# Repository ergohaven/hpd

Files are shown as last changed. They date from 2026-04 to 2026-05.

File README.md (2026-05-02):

## High Plains Drifter is a modular, curved mechanical keyboard that is ready to change the way you think about ergonomics in typing!  
*Innovative design that allows easy access to all keys, and specially designed modules that make the keyboard a unique tool, exclusively for your purpose*

HPD v2

## Design philosphy
This keyboard was designed with FDM printing in mind, the goal was to create a perfect curved case that can be easily printed and looks aesthetically pleasing with minimal amount of so called "steps" that plague similar 3D keyboards like Dactyl Manuform, it's design is similar to the [Velvet v3](https://github.com/ergohaven/velvet) keyboard but with 60% layout and addition of various interchangeable modules
HPD v2
HPD v2

## Features
- Modular, ergonomic 3D design
- 60 fully programmable keys, 15 additional layers for all your tasks
- Powered by RP2040 Zero and QMK firmware
- Hotswappable PCB (MX sockets) 
- Type-C output for connection between halves
- Easily remap any key and customize your keyboard with [Vial](https://eh.industries/vial) 
- [Firmware](https://github.com/ergohaven/keymap_hub) is being constantly updated, get the latest QMK features for your keyboard from us ♥️  

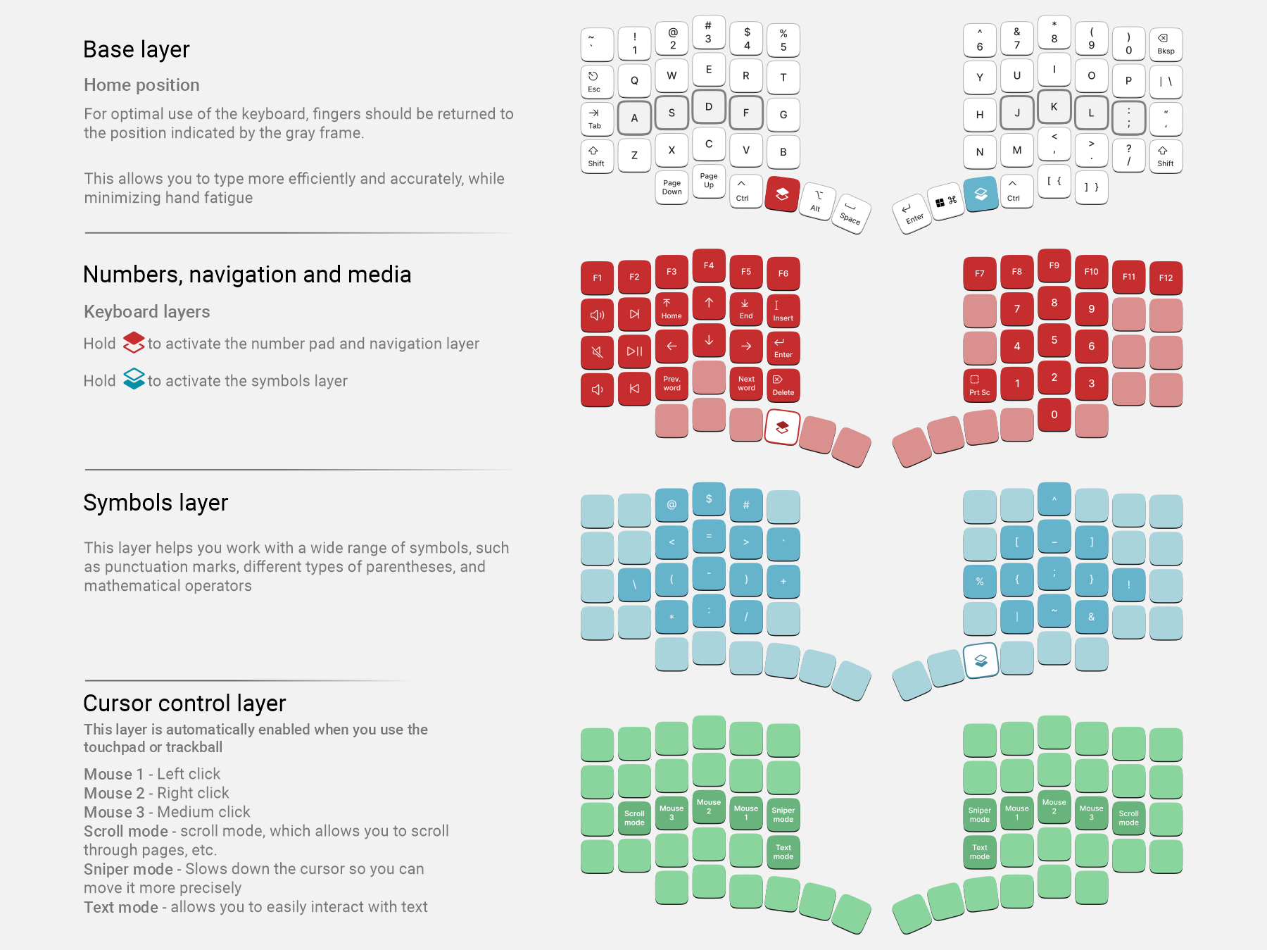
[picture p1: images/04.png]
HPD v2


## This repo contains all files related to this keyboard
PCB and schematic can be found [here](https://oshwlab.com/yuriiq/hpdv2)

### Build guide (handwired)
- [English](https://github.com/ergohaven/hpd/blob/main/handwired/handwired.en.md)
- [Russian](https://github.com/ergohaven/hpd/blob/main/handwired/handwired.md)

### Build guide (PCB is required)
- [English](https://github.com/ergohaven/hpd/blob/main/build_guide/build_guide_en.md)
- [Russian](https://github.com/ergohaven/hpd/blob/main/build_guide/build_guide_ru.md)

### BOM
#### Main case
| Components | Quantity (pcs) |
| --- | ---: |
| Switchplate + thumb keys + MCU holder PCBs | 1 |
| RP2040 Zero MCU | 2 |
| MX Hotswap sockets | 60 |
| 1N4148W Diodes (SOD-123) | 60 |
| Male Pin Header Connector: 11 Pins, 2.54mm, 90 degree | 2 |
| Female Header Sockets: 11 Pins, 2.54mm, 90 degree | 2 |
| Female Header Sockets: 9 Pins, 2.54mm, 90 degree | 2 |
| Socket SH1.0 5 Pins, 1.00mm | 4 |
| Cable connector SH1.0 5 Pins, 1mm, 100mm, double head | 2 |
| 1 - 100 kOhm resistors (0805) | 2 |
| USB Type-C daughterboard: 1.6mm thick | 2 |
| M2x4 Screws | 32 |
| M3x5 Inserts | 10 |
| M3x4 Screws | 10 |
| Magnets (5х10х2mm) | 4 |
| 3M bumpons (8mm) | 4 |

#### Encoder module
| Components | Quantity (pcs) |
| --- | ---: |
| Encoder PCB | 1 |
| Encoder EC11 | 1 |
| Encoder cap | 1 |
| Male Pin Header Connector: 9 Pins, 2.54mm, 90 degree | 1 |
| 1N4148W Diodes (SOD-123) | 1 |
| LED SK6812 mini-e | 1 |
| Magnets (5х10х2mm) | 2 |
| 3M bumpons (8mm) | 2 |

#### Touchpad module
| Components | Quantity (pcs) |
| --- | ---: |
| Touchpad PCB | 1 |
| Azoteq TPS43 | 1 |
| Male Pin Header Connector: 9 Pins, 2.54mm, 90 degree | 1 |
| Connector PH2.0 4 pins, 2mm, 90 degree | 1 |
| Cable connector PH2.0 4 Pins, 2mm, 6mm, one head | 1 |
| Magnets (5х10х2mm) | 2 |
| plate 40x43x1 mm with rounding 3mm | 1 |
| PVC 40x43 mm sticker with rounding 3mm | 1 |
| 3M bumpons (8mm) | 2 |

#### Trackball module
| Components | Quantity (pcs) |
| --- | ---: |
| Trackball PCB | 1 |
| PWM3389 sensor | 1 |
| TPS73601DBVR | 1 |
| Male Pin Header Connector: 9 Pins, 2.54mm, 90 degree | 1 |
| Resistor 0805 10 kOm | 1 |
| Resistor 0805 39 Om | 1 |
| Resistor 0805 37.4 kOm | 1 |
| Resistor 0805 63.4 kOm | 1 |
| Capacitor 0805 100 nF | 3 |
| Capacitor 0805 1 uF | 1 |
| Capacitor 0805 4.7 uF | 1 |
| Capacitor 0805 10 uF | 1 |
| Magnets (5х10х2mm) | 2 |
| 3M bumpons (8mm) | 2 |
| 38mm billiard ball | 1 |
| Ceramic Bearing Balls (3mm) | 3 |

## License 

The files in this repository are licensed under a Creative Commons Attribution-NonCommercial-ShareAlike 4.0 International License.

## Firmware
- [Pre-compiled files][1]
- [Source code][2]

[1]: https://github.com/ergohaven/keymap_hub
[2]: https://github.com/ergohaven/vial-qmk/tree/vial/keyboards/ergohaven

## Availability
The complete keyboard (not a diy kit!) is available for purchase at [eh.industries](https://eh.industries/)

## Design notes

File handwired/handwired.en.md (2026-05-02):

# High Plains Drifter v2 — handwired keyboard assembly guide



## Before you start

This guide describes how to assemble the High Plains Drifter v2 keyboard without PCBs and without complex soldering. It is intended for users who want to build the curved HPD v2 split keyboard at home with minimal cost for parts and tools.

> ⚠️ This guide does not cover assembly of modules for HPD v2, because handwired mounting of components and connectors is not reliable for modules.

## Useful links

- [HPD v2 case for 3D printing (STL)](stl)
- [HPD v2 case model for editing (STEP)](step)
- [HPD v2 circuit schematic](https://oshwlab.com/yuriiq/hpdv2)
- [Firmware](https://github.com/ergohaven/keymap_hub)
- [QMK documentation](https://docs.ergohaven.xyz/qmk/)

---

## Components

| Name | Quantity (pcs) |
| --- | ---: |
| RP2040 Zero MCU | 2 |
| USB Type-C daughterboard: 1.6mm thick | 2 |
| 1N4148 diodes | 60 |
| 1 - 100 kOhm resistors | 2 |
| Hotswap sockets | 60 |
| Switches | 60 |
| Keycaps | 60 |
| M3x5 inserts | 10 |
| M3x4 screws | 10 |
| 3M bumpons (8mm) | 10 |

<details>
<summary><strong>➕ Component appearance</strong></summary>

| Component | Appearance |
| --- | --- |
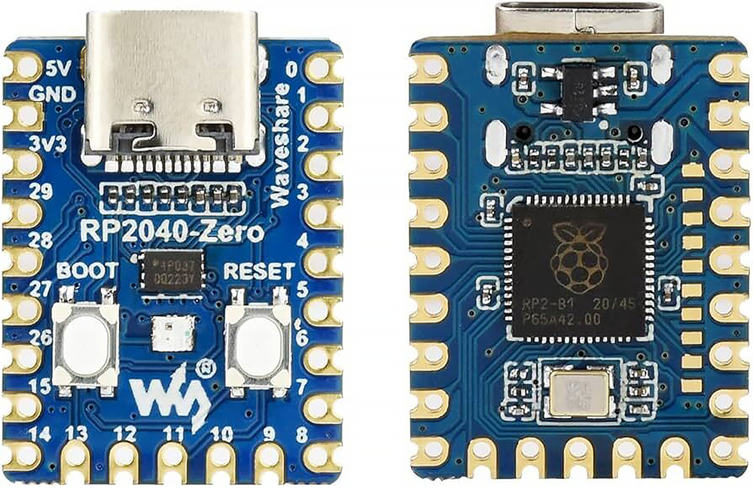
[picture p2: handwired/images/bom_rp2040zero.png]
| RP2040 Zero MCU |  |
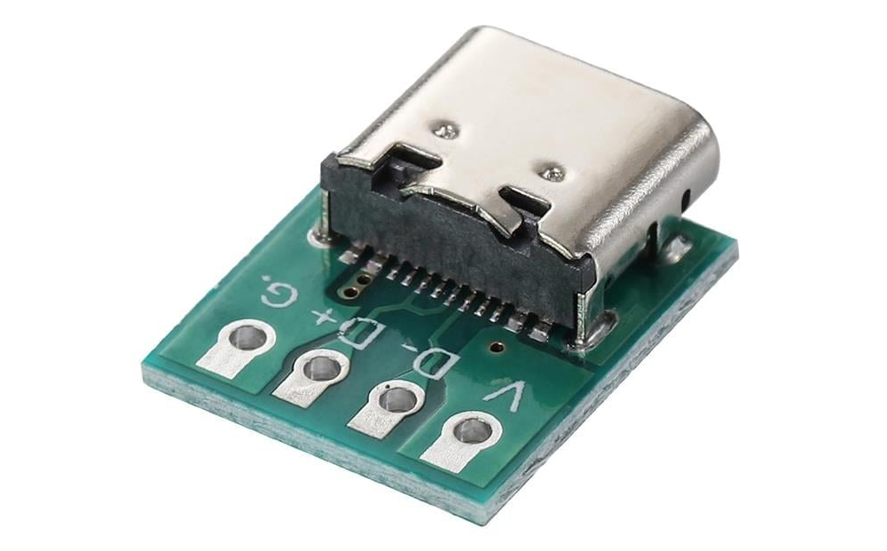
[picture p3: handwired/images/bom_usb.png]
| USB Type-C daughterboard: 1.6mm thick |  |
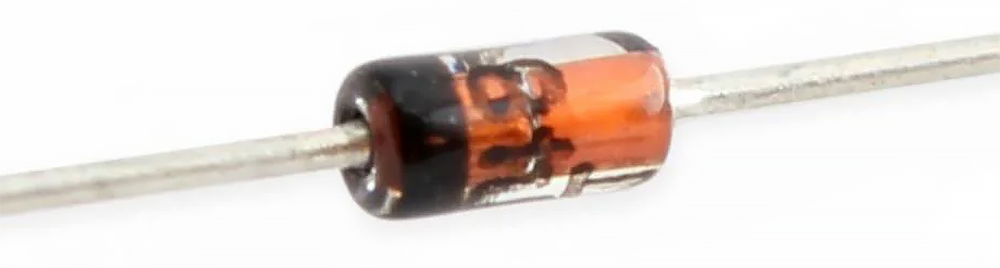
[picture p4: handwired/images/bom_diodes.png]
| 1N4148 diodes |  |
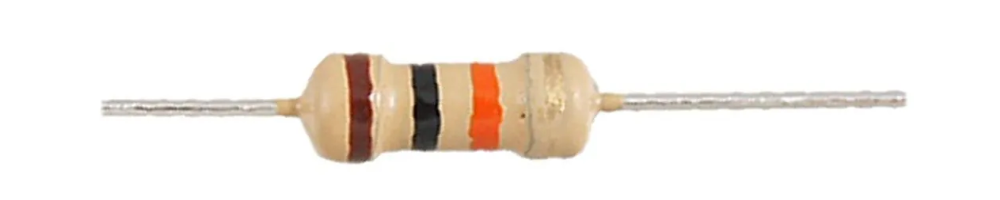
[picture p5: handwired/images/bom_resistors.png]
| 1 - 100 kOhm resistors |  |
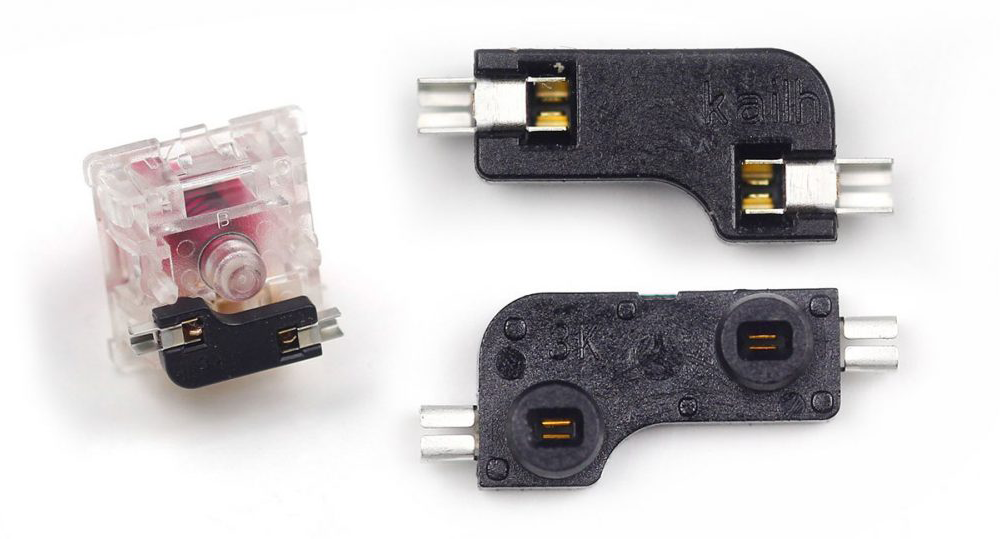
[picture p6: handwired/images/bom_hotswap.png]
| Hotswap sockets |  |
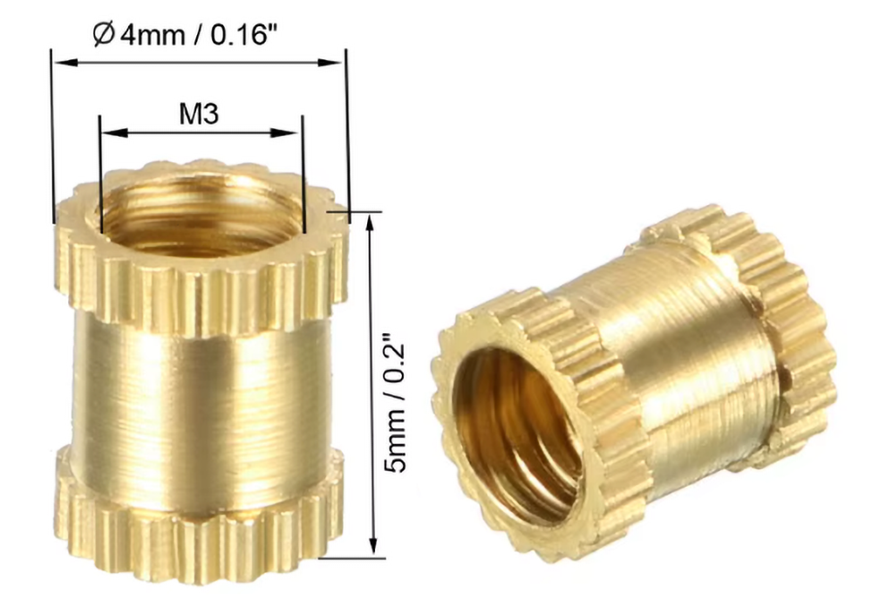
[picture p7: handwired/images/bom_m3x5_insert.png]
| M3x5 inserts |  |
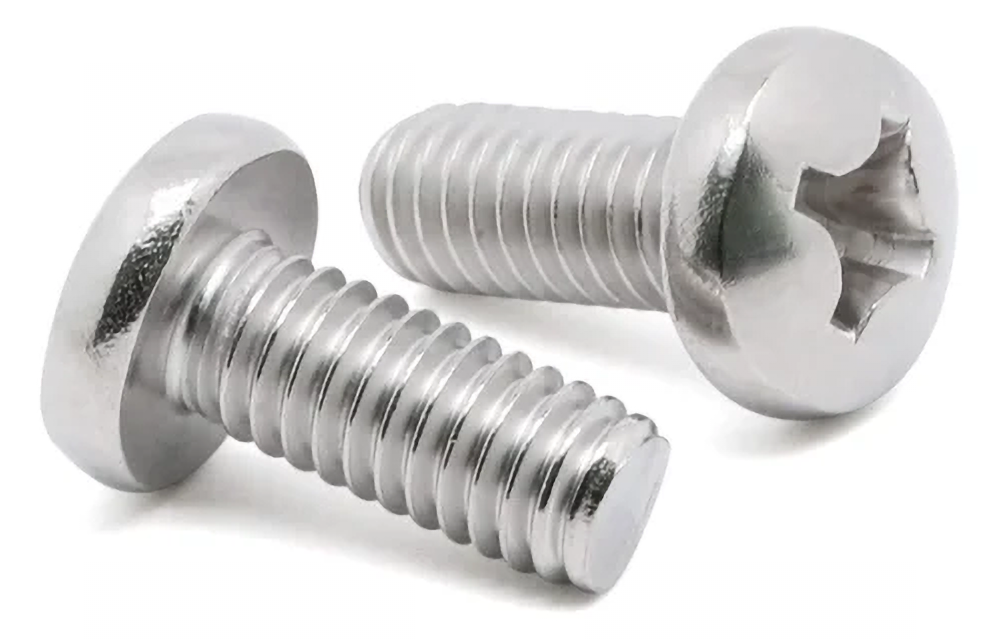
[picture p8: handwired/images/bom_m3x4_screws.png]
| M3x4 screws |  |
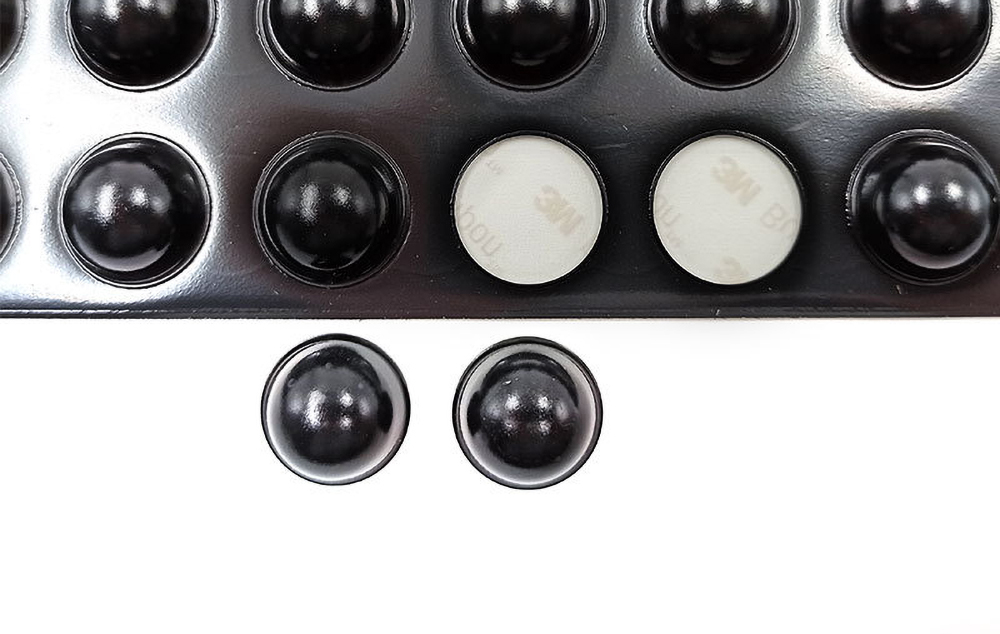
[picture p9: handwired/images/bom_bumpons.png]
| 3M bumpons (8mm) |  |

</details>

---

## Tools and consumables

- 3D printer
- Soldering iron
- Tweezers
- Side cutters
- Screwdriver
- Craft knife
- Solder
- Filament
- Solid-core wire

---

## Assembly steps

### Step 1. Prepare the case, install switches and hotswaps

Print and prepare the [case](stl) on a 3D printer, heat-set the M3x5 inserts, and install the switches and hotswap sockets.



<details>
<summary><strong>➕ Detailed description</strong></summary>

Remove the supports from the case.



Any thin plastic strands in the switch mounting slots can be melted with a lighter.



Heat-set the metal inserts with a soldering iron.




Check that the inserts match the holes in the case cover.



Install the switches on both halves.

> 💡 Insert the switches contact-side down in the top row for easier assembly.




Install the hotswaps on both halves.

> 💡 For the switches in the top row, rotate the hotswaps by 180 degrees.




</details>

---

### Step 2. Prepare the hotswap sockets for soldering

Next, we need to connect all hotswap sockets by columns and rows.

We will connect the rows using 1N4148 diodes. For this, bend the lead on the anode side and trim it, leaving 5–7 mm.



<details>
<summary><strong>➕ Detailed description</strong></summary>

Bend the anode-side lead about 90 degrees.

> ⚠️ The black stripe on the diode marks the cathode; the anode is not marked on the body.



Clip the lead, leaving 5–7 millimeters.



</details>

In this guide we will connect the columns with wires. Prepare them in the required way.

> 💡 You can choose another connection method, for example, use the trimmed diode leads.



<details>
<summary><strong>➕ Detailed description</strong></summary>

Prepare 12 wires about 20 centimeters long. Prepare 8 of them as follows:

- Strip about 15 millimeters of insulation from the end of the wire.



- Make a cut in the insulation about 22 millimeters from the end and slide the insulation toward the end of the wire.



- Make another cut in the insulation about 22 millimeters further and slide the insulation toward the end of the wire.



- Repeat this a third and fourth time. In the end, you should get a wire with 5 exposed segments on the conductor.



For the remaining 4 wires, do the same but with one segment fewer.



</details>

---

### Step 3. Solder the columns and rows

Connect the columns by soldering wires to one of the hotswap socket pins.




<details>
<summary><strong>➕ Detailed description</strong></summary>

> 💡 For convenience, choose one side of the hotswaps for connecting the columns and pre-tin the hotswap contacts with solder.

> ⚠️ Column numbering starts from the side with the USB opening.

The two outer columns (5 and 6) are soldered with wires that have 4 segments, while columns 1–4 use wires with 5 segments prepared in step 2.

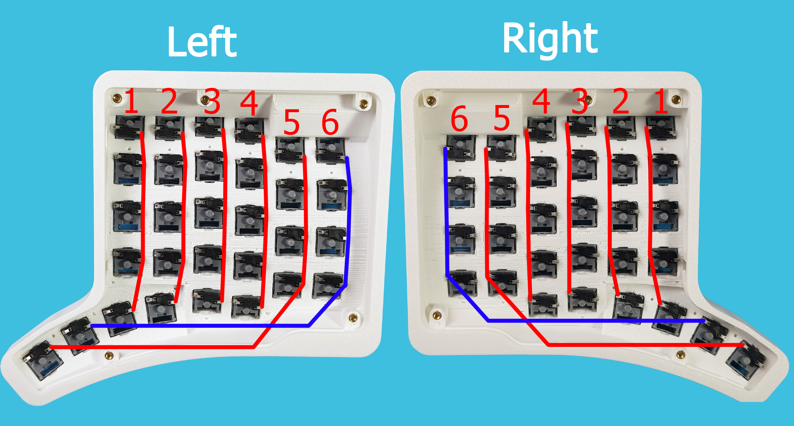
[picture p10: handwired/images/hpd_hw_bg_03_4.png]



Do the same for the right half, mirroring the wire-soldering position.



</details>

Next, connect the rows by soldering 1N4148 diodes with the anode to the second pin of each hotswap socket, and solder a common wire for each row.




<details>
<summary><strong>➕ Detailed description</strong></summary>

Solder the diodes prepared in step 2 to the free hotswap contact with the anode side.

> ⚠️ Row numbering starts from top to bottom.

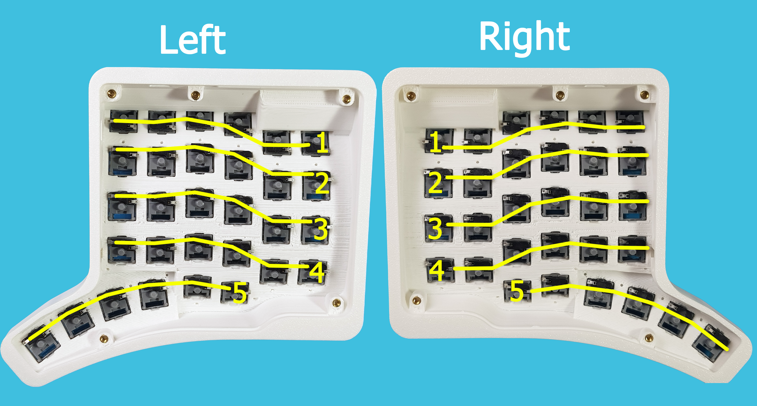
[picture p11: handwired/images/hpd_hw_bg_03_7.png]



Join the cathode leads together into a common trace.



Solder a wire of about 15 centimeters to the common trace.



Repeat these steps for all rows on the left and right halves.

</details>

---

### Step 4. Assemble the holders (controllers)

To assemble the holder (controller), we need two RP2040 Zero controllers, two USB Type-C daughterboards, two 1 - 100 kOhm resistors, and some wires.

Connect everything with wires according to the diagram.

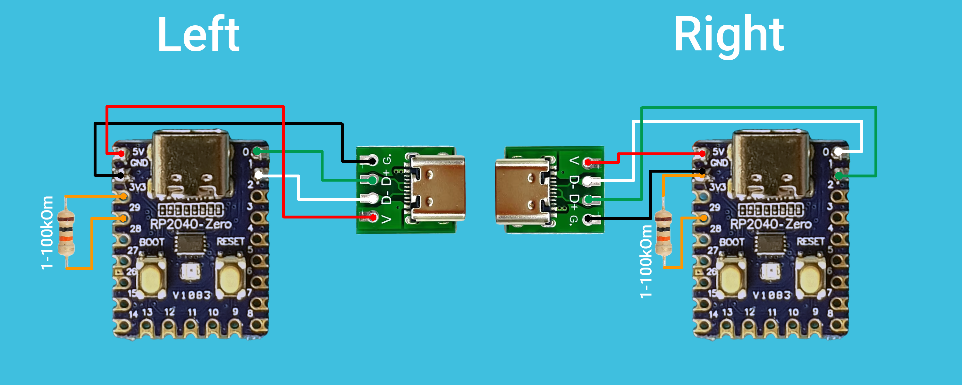
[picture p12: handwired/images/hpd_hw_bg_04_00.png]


First, solder the wires to the USB Type-C daughterboards. For convenience, it is better to use wires of different colors.



Then solder the USB Type-C daughterboards to the RP2040 Zero controller boards.

> ⚠️ On the left and right halves, D- and D+ **are swapped**!

**Left half:**

| USB contact | RP-ZERO pin |
|---|---|
| VCC | 5V |
| GND | GND |
| D− | 0 |
| D+ | 1 |



**Right half:**

| USB contact | RP-ZERO pin |
|---|---|
| VCC | 5V |
| GND | GND |
| D− | 1 |
| D+ | 0 |



Now solder the 1 - 100 kOhm resistors to the RP2040 Zero controllers. This is needed so that the computer can correctly detect which half is connected.

- **Left half:** one end of the resistor → **3V3** pin, the other → **29** pin



- **Right half:** one end of the resistor → **GND** pin, the other → **29** pin



---

### Step 5. Solder the holders (controllers) to the keyboard halves

In this step we will connect the columns and rows to the controller.

Connect everything with wires according to the diagram.

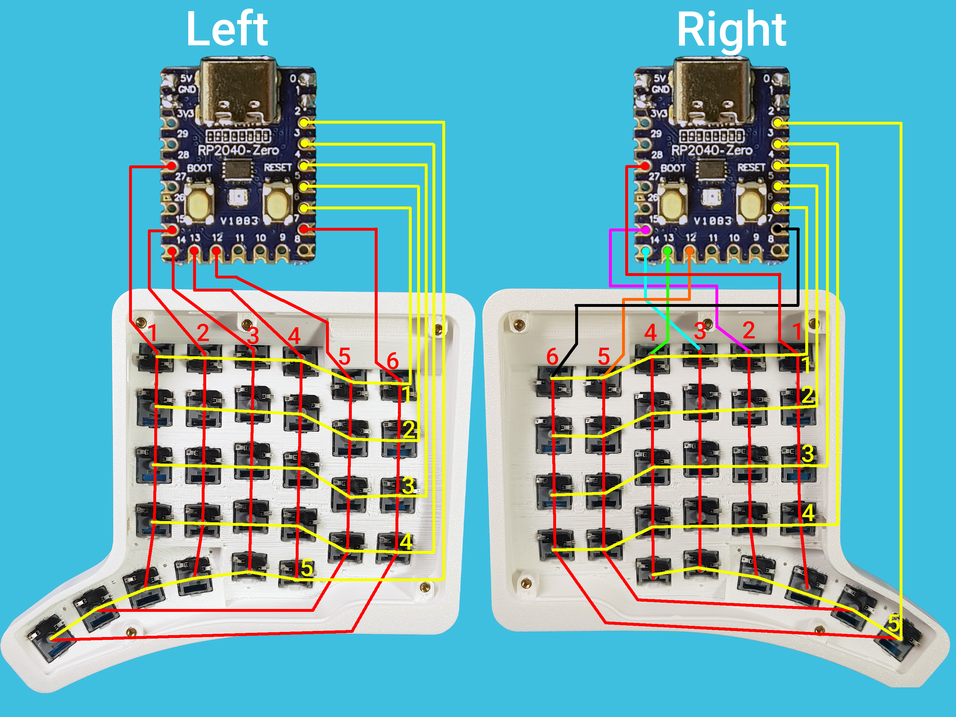
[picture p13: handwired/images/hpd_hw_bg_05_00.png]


#### Columns (vertical key lines)

> ⚠️ Column numbering always starts from the side with the USB opening.

Solder the common wire from the **columns** to the required RP-ZERO pin:

| RP-ZERO pin | Column |
|---|---|
| 28 | 1 |
| 15 | 2 |
| 14 | 3 |
| 13 | 4 |
| 12 | 5 |
| 7 | 6 |

#### Rows (horizontal key lines)

> ⚠️ Row numbering always goes from top to bottom.

| RP-ZERO pin | Row |
|---|-----|
| 6 | 1 |
| 5 | 2 |
| 4 | 3 |
| 3 | 4 |
| 2 | 5 |




---

### Step 6. Final steps

After soldering the controllers to the keyboard halves, it is recommended to check that the keys work correctly.

First, flash both halves:
- connect the USB-C cable from the PC to the controller. If the RPI-RP2 folder does not appear, double-click the **Reset** button on the RP2040 Zero
- copy the firmware file for **HPD v2 (no modules)** from [keymap_hub](https://github.com/ergohaven/keymap_hub) to the root of the RPI-RP2 folder
- repeat the same steps with the other half

After flashing, connect the halves with a USB-C cable and connect them to the PC, open [Vial](https://eh.works/vial), and check both halves in the **Matrix tester**.

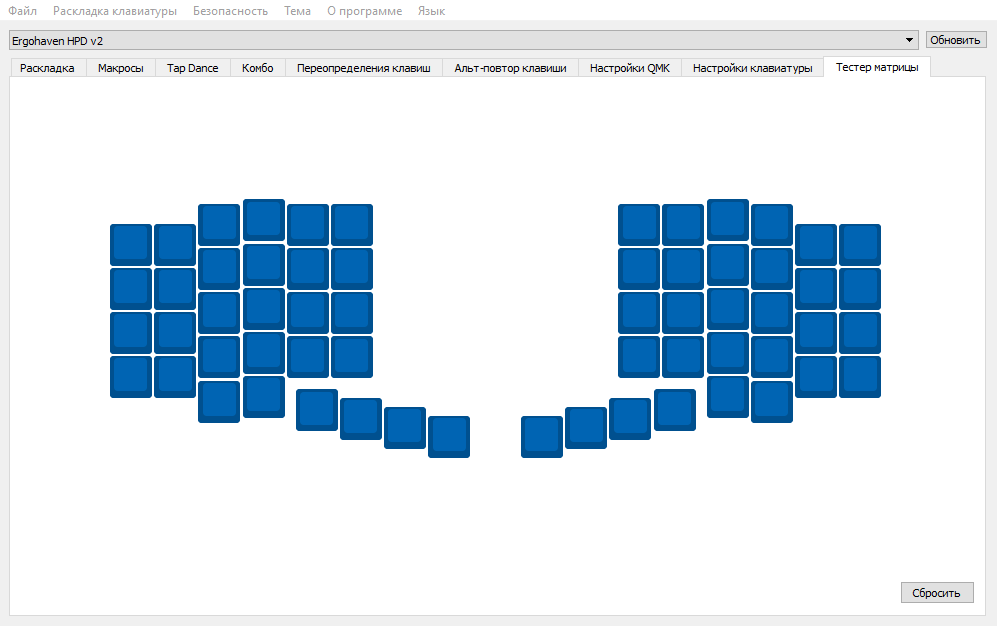
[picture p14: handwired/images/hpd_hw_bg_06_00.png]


<details>
<summary><strong>⁉️ Possible issues and how to fix them</strong></summary>

- **The computer does not see the keyboard, the BOOT drive does not appear**

  Check the board for short circuits, inspect the 3V3, 5V and GND pins. Also check the integrity of the USB connector and its solder joints.

- **An entire column does not work**

  There is no connection between the column and the RP-ZERO. Continuity-test or visually inspect the wire from the hotswap sockets to the required controller pin.

- **A row or part of a row does not work**

  The problem is with the diodes. Check the soldering, one or more diodes may be reversed or not fully soldered.

- **A key or several keys are stuck**

  Somewhere a diode is shorting to a column. Inspect the diode solder joints in the problematic area, look for accidental solder bridges.

- **The halves are mirrored (the left behaves like the right)**

  The resistors are soldered incorrectly. Go back to step 4 and check: on the left half the resistor goes to 3V3, on the right half it goes to GND.

</details>

If the test was successful, continue assembling the halves. Place the controller boards and the side USB-C connector into the printed [holder case](stl/handwired-holder.stl), then screw the assembled holder to the half case.

> ⚠️ To print the left [holder](stl/handwired-holder.stl), mirror the model in the slicer before printing.

On the left half




and on the right half




Then screw on the bottom covers with M3x4 screws and attach the silicone feet (five on each half).




Install the keycaps and side plugs.




### The keyboard is ready!



---

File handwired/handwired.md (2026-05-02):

# High Plains Drifter v2 — руководство по ручной сборке клавиатуры



## Перед началом

В данном руководстве описан процесс сборки клавиатуры High Plains Drifter v2 без применения печатных плат и сложной пайки. Руководство ориентировано на тех пользователей, у кого есть желание собрать изогнутую сплит-клавиатуру HPDv2 в домашних условиях и с минимальными затратами на компоненты и инструменты

> ⚠️ В данном руководстве не затронута сборка модулей для клавиатуры HPDv2, так как навесной монтаж компонентов и разъемов не является надежным для модулей

## Полезные ссылки

- [Корпус HPDv2 для 3D-печати (STL)](stl)
- [Модель корпуса HPDv2 для редактирования (STEP)](step)
- [Электронная схема HPDv2](https://oshwlab.com/yuriiq/hpdv2)
- [Прошивка](https://github.com/ergohaven/keymap_hub)
- [Документация QMK](https://docs.ergohaven.xyz/qmk/)

---

## Компоненты

| Название | Количество (шт) |
| --- | --- |
| RP2040 Zero MCU | 2 |
| USB Type-C daughterboard: 1.6mm thick | 2 |
| 1N4148 Diodes | 60 |
| 1 - 100 kOhm resistors | 2 |
| Hotswap sockets | 60 |
| Switch | 60 |
| Keycaps | 60 |
| M3x5 Inserts | 10 |
| M3x4 Screws | 10 |
| 3M bumpons (8mm) | 10 |

<details>
<summary><strong>➕ Внешний вид компонентов</strong></summary>

| Компонент | Внешний вид |
| --- | --- |
| RP2040 Zero MCU |  |
| USB Type-C daughterboard: 1.6mm thick |  |
| 1N4148 Diodes |  |
| 1 - 100 kOhm resistors |  |
| Hotswap sockets |  |
| M3x5 Inserts |  |
| M3x4 Screws |  |
| 3M bumpons (8mm) |  |

</details>

---

## Инструменты и расходные материалы

- 3D принтер
- Паяльник
- Пинцет
- Кусачки
- Отвёртка
- Канцелярский нож
- Припой
- Филамент
- Провод одножильный 

---

## Порядок сборки

### Шаг 1. Подготовка корпуса, установка свитчей и хотсвапов

Распечатаем и подготовим [корпус](stl) на 3D принтере, вплавим металлические вставки M3x5 и установим свитчи и хотсвапы



<details>
<summary><strong>➕ Подробное описание</strong></summary>

Корпус очищаем от поддержек



Тонкие нити пластика в посадочных местах для свитчей можно оплавить зажигалкой



Вплавляем металлические вставки паяльником




Проверяем на соответствие металлические вставки и отверстия на крышке корпуса



Вставляем свитчи на обе половинки 
> 💡 Вставим свитчи контактами вниз в верхний ряд для удобства сборки




Вставляем хотсвапы на обе половинки 
> 💡 Для свитчей верхнего ряда разверните хотсвапы на 180 градусов




</details>

---

### Шаг 2. Подготовка к пайке хотсвап сокетов

Далее нам потребуется соединить все хотсвап сокеты по столбцам и рядам

Ряды будем соединять с помощью диодов 1N4148, для этого со стороны анода загнем вывод и откусим его, оставив 5-7мм 



<details>
<summary><strong>➕ Подробное описание</strong></summary>
  
Со стороны анода загнем ножку примерно на 90 градусов
> ⚠️ У диода черной полоской обозначен катод, анод - не маркируется на корпусе



Кусачками откусим ножку, оставив 5-7 миллиметров 



</details>

В данном руководстве столбцы соединим при помощи проводков, для этого подготовим их определенным способом 
> 💡 Вы можете выбрать другой способ соединения, например, использовать остатки от ножек диодов)



<details>
<summary><strong>➕ Подробное описание</strong></summary>

Заготовим 12 проводков по ~20 сантиметров, 8 из них подготовим следующим образом:
- Зачистим изоляцию на конце проводка на ~15 миллиметров



- Сделаем надрез на изоляции на расстоянии ~22 миллиметра и сдвинем изоляцию к концу проводка



- Снова делаем надрез на изоляции на расстоянии ~22 миллиметра и сдвинем изоляцию к концу проводка



- Повторяем это же действие в третий и четвертый раз, по итогу должен получиться проводок с 5 оголенными сегментами на жиле



Для оставшихся 4 проводков проделаем то же самое, но на один сегмент меньше



</details>

---

### Шаг 3. Пайка столбцов и рядов

Соединим столбцы, для этого припаиваем проводки к одному из выводов хотсвап сокета




<details>
<summary><strong>➕ Подробное описание</strong></summary>

> 💡 Для удобства нужно выбрать одну сторону у хотсвапов для соединения столбцов и предварительно залудить контакты хотсвапа припоем

> ⚠️ Отсчёт столбцов начинается со стороны отверстия для USB

Крайние два столбца (5 и 6) приваиваем проводками с 4 сегментами, а 1-4 столбцы - проводками с 5 сегментами, которые мы заготовили в шаге 2




Делаем те же действия для правой половинки, отзеркалив положение пайки проводков



</details>

Далее соединим ряды, для этого припаиваем диоды 1N4148 анодом ко второму выводу хотсвапа и припаиваем общий провод от каждого ряда




<details>
<summary><strong>➕ Подробное описание</strong></summary>

Подготовленные в шаге 2 диоды припаиваем анодом к свободному контакту хотсвапа 
> ⚠️ Отсчёт рядов начинается сверху вниз




Соединяем ножки катодов вместе (в общую дорожку)



Припаиваем к общей дорожке припаиваем провод (~15 сантиметров)



Повторяем эти шаги для всех рядов левой и правой половинок

</details>

---

### Шаг 4. Сборка холдеров (контроллеров)

Для сборки холдера (контроллера) нам потребуется два контрорллера RP2040 Zero, две платы с разъемом USB Type-C, два резистора на 1 - 100 kOhm и немного проводков

Соединяем (припаиваем) проводками согласно схеме



Первым делом припаиваем провода к платам с разъемом USB Type-C (для удобства лучше использовать проводки различных цветов)



Далее, припаиваем платы с разъемом USB Type-C к платам контроллерам RP2040 Zero

> ⚠️У левой и правой половинок D- и D+ **меняются местами**!

**Левая половинка:**

| USB контакт | Пин RP-ZERO |
|---|---|
| VCC | 5V |
| GND | GND |
| D− | 0 |
| D+ | 1 |



**Правая половинка:**

| USB контакт | Пин RP-ZERO |
|---|---|
| VCC | 5V |
| GND | GND |
| D− | 1 |
| D+ | 0 |



Теперь припаиваем резиторы на 1 - 100 kOhm к контроллерам RP2040 Zero. Это нужно, чтобы компьютер правильно определил, какую половинку подключили

- **Левая половинка:** один конец резистора → пин **3V3**, другой → пин **29**



- **Правая половинка:** один конец резистора → пин **GND**, другой → пин **29**



---

### Шаг 5. Пайка холдеров (контроллеров) к половинкам клавиатуры

В этом шаге соединим столбцы и ряды с контроллером

Соединяем (припаиваем) проводками согласно схеме



#### Столбцы (вертикальные линии клавиш)

>⚠️ Отсчёт столбцов всегда начинается со стороны отверстия для USB

Припаиваем общий провод от **столбцов** к нужному пину RP-ZERO:

| Пин RP-ZERO | Столбец |
|---|---|
| 28 | 1 |
| 15 | 2 |
| 14 | 3 |
| 13 | 4 |
| 12 | 5 |
| 7 | 6 |

#### Ряды (горизонтальные линии клавиш)

>⚠️ Отсчёт рядов — всегда сверху вниз

| Пин RP-ZERO | Ряд |
|---|-----|
| 6 | 1 |
| 5 | 2 |
| 4 | 3 |
| 3 | 4 |
| 2 | 5 |




---

### Шаг 6. Финальные действия

После припаивания контроллеров к половинкам клавиатуры рекомендуется проверить клавиши на корректную работу

Для начала нужно прошить обе половинки: 
- подключите кабель USB-C от ПК к контроллеру, если не отрылась папка контроллера RPI-RP2, то дважды быстро нажмите на кнопку **Reset** на RP2040 Zero
- скопируйте файл прошивки для **HPD v2 (no modules)** из [keymap_hub](https://github.com/ergohaven/keymap_hub) в корень папки контроллера RPI-RP2 
- повторите те же действия с другой половинкой 

После прошивки соедините половинки между собой кабелем USB-C и подключите к ПК, откройте [Vial](https://eh.works/vial) и проверьте половинки в **Тестере матрицы (Matrix tester)**



<details>
<summary><strong>⁉️ Возможные ошибки и способы их устранения</strong></summary>

- **Компьютер не видит клавиатуру, не появляется BOOT-диск**

Проверьте плату на наличие короткого замыкания — осмотрите пины 3V3, 5V и GND. Также проверьте целостность USB-разъёма и пайку к нему

- **Не работает целый столбец**

Нет связи между столбцом и RP-ZERO. Прозвоните или визуально проверьте провод столбца от хотсвап сокетов до нужного пина контроллера

- **Не работает ряд или часть ряда**

Проблема в диодах. Проверьте пайку — возможно, один или несколько диодов перевёрнуты или не припаяны до конца

- **Залипает клавиша или несколько клавиш**

Где-то диод замыкает на столбец. Осмотрите пайку диодов в проблемной зоне — ищи случайные перемычки припоя

- **Половинки отзеркалены (левая ведёт себя как правая)**

Резисторы припаяны неправильно. Вернитесь к шагу 4 и проверьте: на левой половинке резистор идёт на 3V3, на правой — на GND

</details>

Если тест прошел успешно, то собираем половинки дальше. В распечатанный [корпус холдера](stl/handwired-holder.stl) вставляем платы контроллера и бокового USB-C разъема, прикручиваем собранный холдер к корпусу половинки

>⚠️ Для печати левого [холдера](stl/handwired-holder.stl) отзеркальте модель в слайсере перед печатью

на левой половинке




и на правой половинке




Далее прикручиваем нижние крышки винтами M3x4 и наклеиваем силиконовые ножки (по пять штук на каждую половинку)




Ставим кейкапы и боковые заглушки 




### Клавиатура готова! 



---

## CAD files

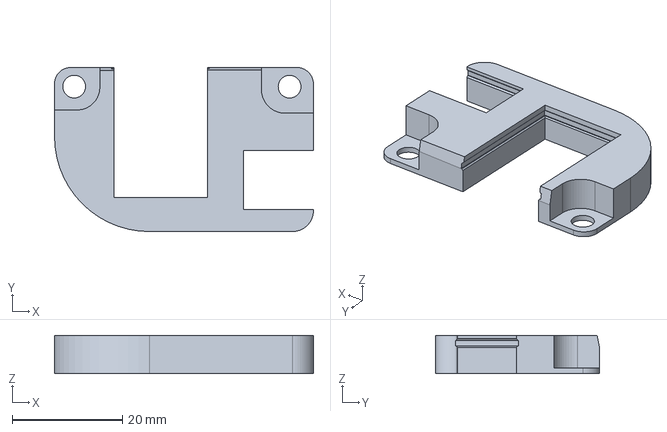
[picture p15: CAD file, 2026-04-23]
handwired/step/handwired-holder.stp
47.0 x 29.8 x 6.94 mm

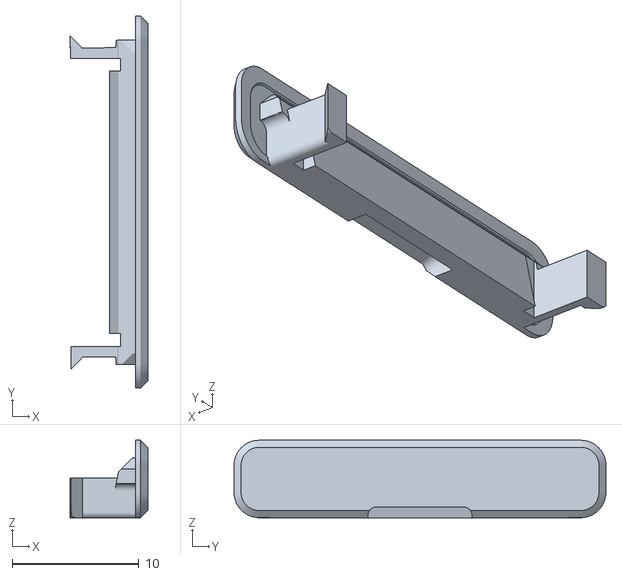
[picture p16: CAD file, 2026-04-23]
handwired/stl/handwired-module-stub.stl
6.12 x 29.3 x 6.12

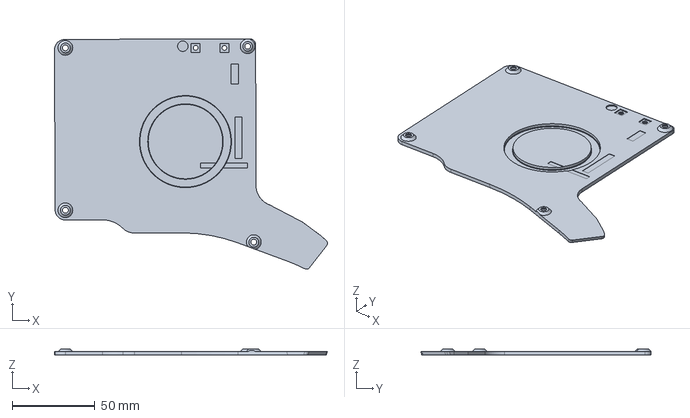
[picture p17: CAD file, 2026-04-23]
step/bot-left.stp
164.6 x 138.9 x 3.80 mm

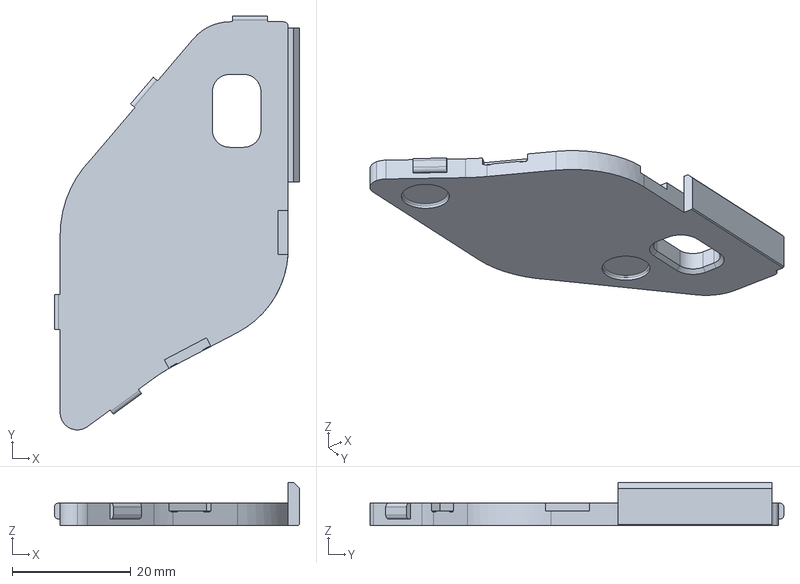
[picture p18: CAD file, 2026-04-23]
step/modules/joystick-bot.stp
41.3 x 69.7 x 7.28 mm

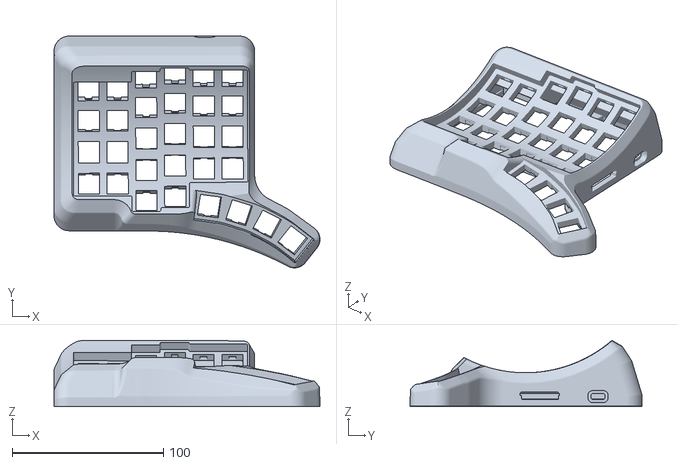
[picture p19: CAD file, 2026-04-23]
stl/body-left.stl
175.7 x 153.1 x 43.8

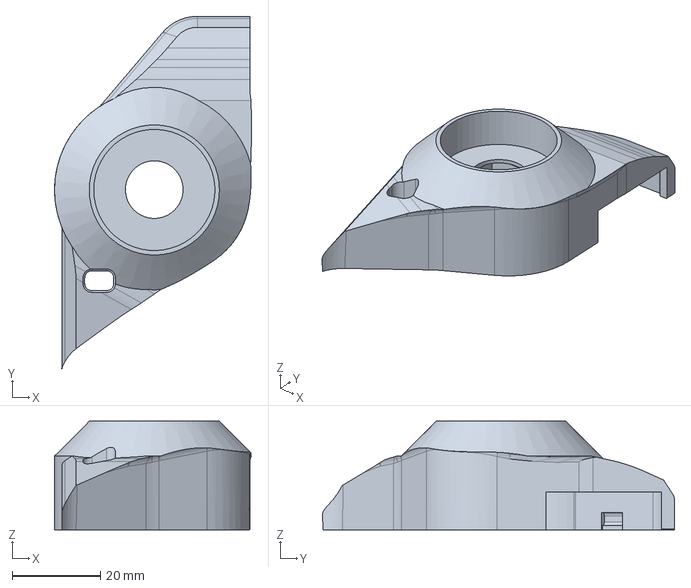
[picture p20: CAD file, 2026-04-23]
step/modules/encoder-right-body-BL.stp
44.7 x 80.0 x 24.7 mm

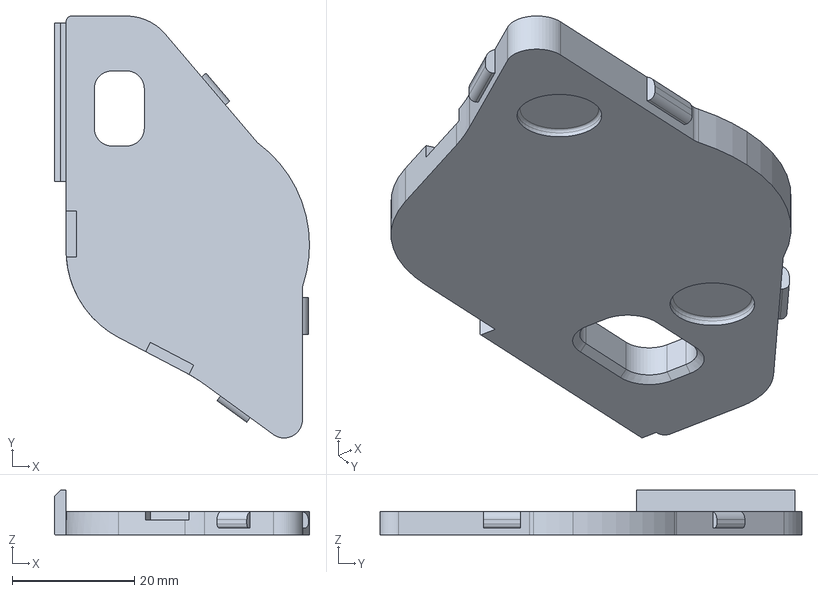
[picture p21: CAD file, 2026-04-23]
step/modules/encoder-left-bot.stp
41.7 x 69.0 x 7.28 mm

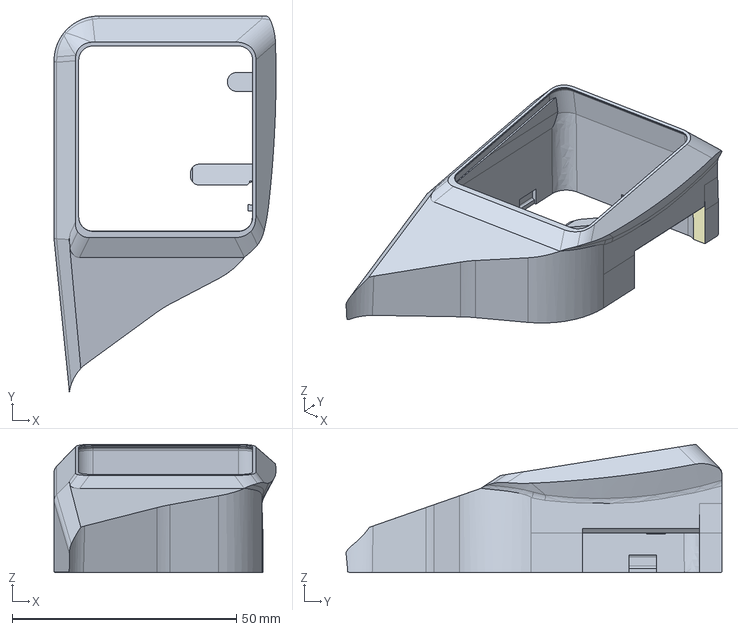
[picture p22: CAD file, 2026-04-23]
step/modules/touchpad-body.stp
49.5 x 83.8 x 28.7 mm

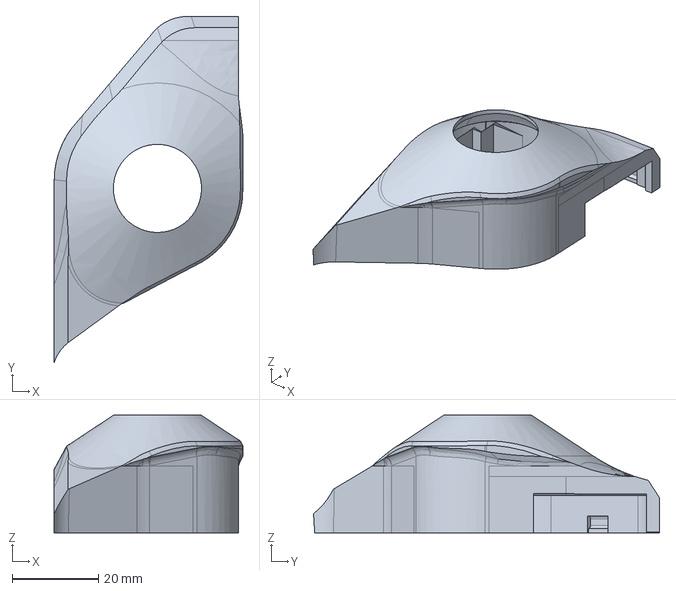
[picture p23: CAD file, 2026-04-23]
step/modules/joystick-body.stp
43.6 x 80.0 x 27.2 mm

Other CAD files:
handwired/step/handwired-bot-left.stp
step/bot-right.stp
stl/body-right.stl
handwired/step/handwired-bot-right.stp
handwired/stl/handwired-body-right.stl
step/modules/encoder-left-body-BL.stp
step/modules/encoder-right-bot.stp
handwired/stl/handwired-bot-left.stl
handwired/stl/handwired-bot-right.stl
handwired/stl/handwired-holder.stl
step/modules/encoder-left-body.stp
step/modules/encoder-right-body.stp
step/modules/touchpad-bot.stp
step/modules/trackball-body.stp
step/modules/trackball-bot.stp
stl/bot-left.stl
stl/bot-right.stl
stl/modules/encoder-left-body-bl.stl
stl/modules/encoder-left-body.stl
stl/modules/encoder-left-bot.stl
stl/modules/encoder-right-body-bl.stl
stl/modules/encoder-right-body.stl
stl/modules/encoder-right-bot.stl
stl/modules/joystick-body.stl
stl/modules/joystick-bot.stl
stl/modules/touchpad-body.stl
stl/modules/touchpad-bot.stl
stl/modules/trackball-body.stl
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

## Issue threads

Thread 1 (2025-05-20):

trackball case design change?

tangbonze, 2025-05-20:
Hi there:
I found there are differences between trackball case stl file and buildguide. Could you please explain a little about how to assemble using case file?
Thank in advanced.

lotabout, 2025-09-02:
@kissetfall

Thank you so much for sharing the keyboard design. However, I also noticed that the STL file differs from what’s shown in the build guide. After doing some research, it also seems that using a static bearing ball might be a better solution. Would you be able to share that design as well? Thanks!

Большое спасибо за то, что поделились дизайном клавиатуры. Однако я заметил, что файл STL отличается от того, что показано в руководстве по сборке. После небольшого исследования я также пришёл к выводу, что использование неподвижного шарикоподшипника может быть лучшим решением. Не могли бы вы поделиться и этим дизайном? Спасибо!

kissetfall, 2025-09-05:
Noted, will update soon

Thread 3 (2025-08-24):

Module and non-module firmware compatability

siege9929, 2025-08-24:
Right now I have a hand-wired HPDv2 with an encoder on the left and nothing on the right.
If I install the encoder+whatever module firmware on the left half, it stops communicating with the non-module firmware on the right half.
If I install the same firmware on the right half that I installed on the left half (in this case encoder+joystick), the missing joystick hardware causes the mouse cursor to drift randomly (presumably caused by floating pins).

Would it be possible to update the firmware files to work with other module firmware?
Maybe it's better to make each firmware support one module specifically (and leave one for no modules) and then we flash the correct module firmware to each half.

kissetfall, 2025-09-05:
This request should be asked in our vial-qmk repo.

Closed 2025-09-05.

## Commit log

2026-03-31 Add build guide image: firmware-test-wired.jpg
2026-03-31 Add build guide image: rp-zero-resistor-complete.png
2026-03-31 Add build guide image: rp-zero-wires-keyboard.png
2026-03-31 Add build guide image: rp-zero-wires-start.png
2026-03-31 Add build guide image: usb-c-wires.png
2026-03-31 Revert: remove build_guide/handmake/images/firmware-test-wired.jpg
2026-03-31 Revert: remove build_guide/handmake/images/rp-zero-resistor-complete.png
2026-03-31 Revert: remove build_guide/handmake/images/rp-zero-wires-keyboard.png
2026-03-31 Revert: remove build_guide/handmake/images/rp-zero-wires-start.png
2026-03-31 Revert: remove build_guide/handmake/images/usb-c-wires.png
2026-03-31 Add image: firmware-test-wired.jpg
2026-03-31 Add image: usb-c-wires.png
2026-03-31 Add new build guide image: diodes-bent-leg.png
2026-03-31 Remove photo numbering, add camera emoji to captions
2026-03-31 Add new images to 'Подготовка перед пайкой' and update photo captions
2026-03-31 Add new build guide image: trimmed-diode-legs-new.jpg
2026-03-31 Insert new photos for diode preparation, update refs and ensure consistent captions
2026-04-01 Add screw M3x5 and heat inserts M3 to components list
2026-04-01 Add case prep image: heat-insert-closeup.jpg
2026-04-01 Add step 5 image: keyboard-wired-open.jpg
2026-04-01 Update components: remove drafts, add resistor photo, clean up
2026-04-01 Add component photos: RP2040-Zero, USB-C, diode, switches
2026-04-08 replace layouts .png
    updating current layout
2026-04-08 Format main case BOM as table
2026-04-08 Update trackball module BOM
2026-04-08 update stl and step
    [body-left.stl, body-right.stl, bot-left.stl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]
2026-04-08 correct folder stl and step
    [body-left.stl, body-right.stl, bot-left.stl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]
